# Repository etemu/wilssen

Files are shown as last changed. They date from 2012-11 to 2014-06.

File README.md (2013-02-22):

wilssen
=======

Wireless / Wind Logging System for Sourcing ENergy - "Wilssen" is a modular controller for e.g. a wind turbine, it monitors all parameters like phase voltage and efficiency when the wind turbine is generating power.

Compatible with the the Arduino platform.

CC-BY-SA 3.0: This work is Open Source and licensed under
the Creative Commons Attribution-ShareAlike 3.0 License.

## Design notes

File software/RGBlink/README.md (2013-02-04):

#RGBlink

An Arduino library for controlling RGB-leds non-blocking

[Documentation](http://docs.l3kn.de/RGBlink/)

by Leon (l3kn) Rische

CC-BY-SA 3.0: This work is Open Source and licensed under the Creative Commons Attribution-ShareAlike 3.0 License.

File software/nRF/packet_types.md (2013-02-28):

# Nodes (N-Packet)

Sent by the 000-Node, containing all 'active' nodes (id, ping)
When recvived, add new nodes to own node-list

# Time (T-packet)

When recived and sent by a node which is not in the reciving nodes list of active nodes, add it to the list.
(send a N-packet?), if recived a new node send it back to it and wait for a ping-packet.

# Ping (P-packet)

(Do fancy foo to determine the hop-delay between nodes)

# values (V-packet)

Send sensor values and time, when recived by a non-000 node, forward it to the reciving nodes parent node.
When recived by the 'exit-node' write it to a logfile/cosm

# LED-Pattern (L-packet)

Dent by the 000-node, when recived, forward it to all child-nodes, delay (until every node recived it) and blink the pattern.

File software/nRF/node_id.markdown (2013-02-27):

# Node-ID

15-bit long, octal system > 5x(0..7), in this case only 5x(0..4) because a node can only have 5 receiving-pipes.

The exit node has the ID 00000, the highest possible node is 55555, which means there can be 5^5=3125 nodes.

* Node 00000 has 5 child-nodes, (00001..00005)  
* Node 00001 has 5 child-nodes, (00011..00051)  
* Node 00011 has 5 child-nodes, (00111..00511) 

and so on.

## parent node

To get a nodes parent node, we need to create a mask for the node_id:

To archive this, we take an "full" octal value and shift it right by one digit (3 bits) until there are only 0s in the mask, where there are non-0 digits in the ID.

Then we need to invert the result to a mask of all non-0 digits.

``` c
uint16_t check = 017777;
uint16_t id = 0321;
while ( id & check )
{
	check <<= 3;
	printf("%o\n", check);
	printf("%o\n", id);
}
```
*note: all numbers are octal*

>177770
>000321
>177700
>000321
>177000
>000321

-> mask = 000777

## parent pipe

To communicate each node needs to know, to which of its parents 5 pipes it is connected to, for once 000321 this would be 3, or the node_id - the parent_id shifted to right by the length of the parent_id:

>parent_id = 21  
>node_id = 321  
>node_id - parent_id = 300  
>parent_id.lenght = 2  
>(node_id - parent_id)>>(parent_id.lenght*3) = 3

or written in C

``` c
foo = parent_id
bar = node_id

while(parent_id)
{
	foo>>=3;
	bar>>=3;
}

print bar
```

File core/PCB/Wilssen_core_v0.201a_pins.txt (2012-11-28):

Pinlist

Exported from Wilssen_core_v0.201a.brd at 29.11.2012 00:44:35

EAGLE Version 6.3.0 Copyright (c) 1988-2012 CadSoft

Part     Pad      Net

ATMEGA168/ATMEGA328 1        D3
         10       D6
         11       D7
         12       D8
         13       D9
         14       D10
         15       MOSI
         16       MISO
         17       SCK
         18       VCC
         19       A6
         2        D4
         20       VCC
         21       GND
         22       A7
         23       A0
         24       A1
         25       A2
         26       A3
         27       A4
         28       A5
         29       RST1
         3        GND
         30       RXI
         31       TXO
         32       D2
         4        VCC
         5        GND
         6        VCC
         7        XTAL1
         8        XTAL2
         9        D5

C1       A        VCC
         C        GND

C2       1        VCC
         2        GND

C4       1        GND
         2        A0

C5       1        GND
         2        XTAL1

C6       1        GND
         2        XTAL2

C9       1        USB_VIN
         2        GND

C10      1        VBATT
         2        GND

D1       A        N$2
         C        GND

D4       A        VBATT
         C        N$8

JP1      1        VCC
         10       D9
         11       D10
         12       MOSI
         13       MISO
         14       SCK
         2        GND
         3        D2
         4        D3
         5        D4
         6        D5
         7        D6
         8        D7
         9        D8

JP2      1        GND
         2        VBATT

JP3      1        GND
         2        VBATT
         NC1               *** unconnected ***
         NC2               *** unconnected ***

JP4      1        MISO
         2        VCC
         3        SCK
         4        N$1
         5        RST
         6        GND

JP6      1        GND
         2        USB_VIN

JP8      1        A0
         2        A1
         3        A2
         4        A3
         5        A4
         6        A5
         7        A6
         8        A7

JP9      1        GND
         2        AREF
         3        VCC
         4        RXI
         5        TXO
         6        DTR

Q1       1        XTAL2
         2        XTAL1

R1       1        SCK
         2        N$2

R2       1        GND
         2        A0

R3       1        A0
         2        VBATT

R4       1        RST
         2        VCC

R5       1        N$1
         2        MOSI

R9       1        N$11
         2        N$8

U1       1                 *** unconnected ***
         2        GND
         3        N$11
         4        USB_VIN
         5        VBATT

U2       1        VBATT
         2        GND
         3        VBATT
         4                 *** unconnected ***
         5        VCC

U3       1        D3
         10       D6
         11       D7
         12       D8
         13       D9
         14       D10
         15       MOSI
         16       MISO
         17       SCK
         18       VCC
         19       A6
         2        D4
         20                *** unconnected ***
         21       GND
         22       A7
         23       A0
         24       A1
         25       A2
         26       A3
         27       A4
         28       A5
         29       RST
         3        GND
         30       RXI
         31       TXO
         32       D2
         4        VCC
         5        GND
         6        VCC
         7        XTAL1
         8        XTAL2
         9        D5

X1       D+                *** unconnected ***
         D-                *** unconnected ***
         GND      GND
         GND@1             *** unconnected ***
         GND@2             *** unconnected ***
         GND@3             *** unconnected ***
         GND@4             *** unconnected ***
         ID                *** unconnected ***
         VBUS     USB_VIN

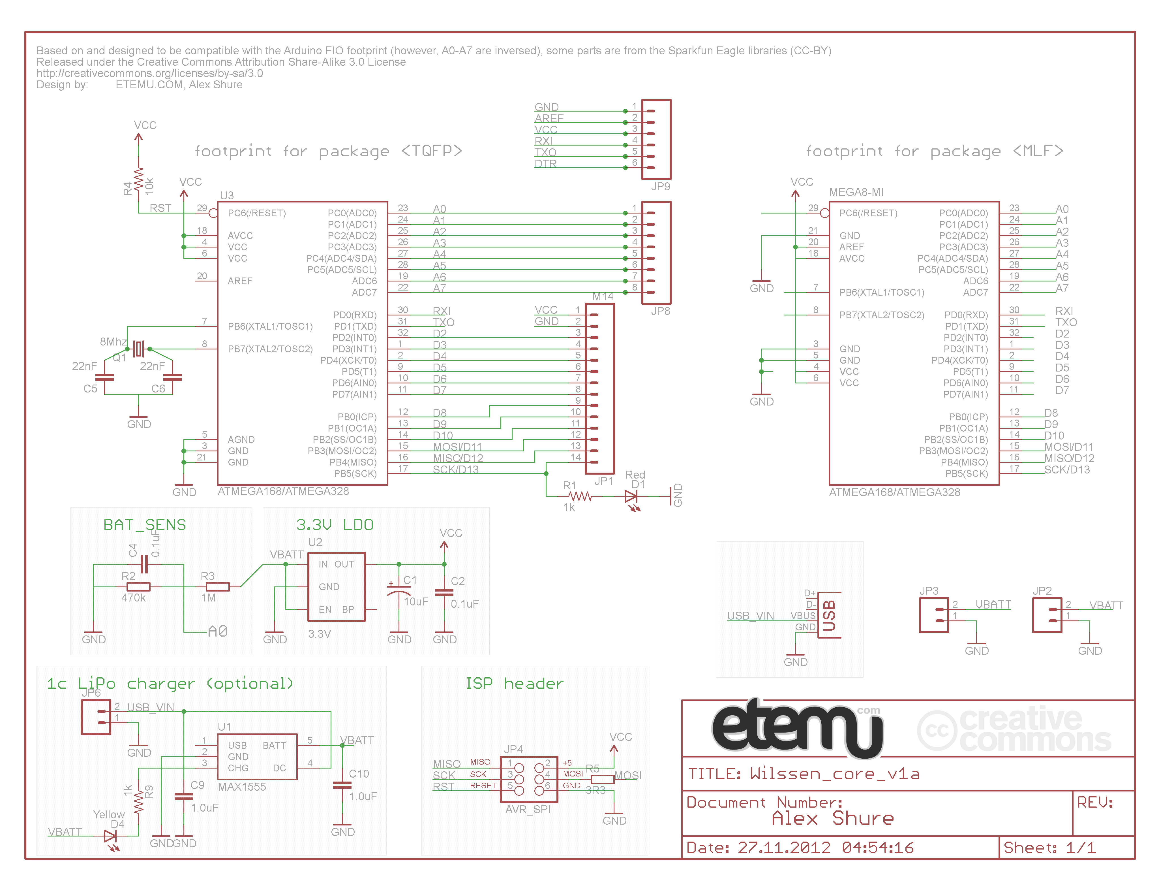
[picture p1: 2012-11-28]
core/PCB/Wilssen_core_v0.201a.sch(201211270426_Wilssen_core_schematic).png

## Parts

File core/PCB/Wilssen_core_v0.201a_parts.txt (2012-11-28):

Partlist

Exported from Wilssen_core_v0.201a.brd at 29.11.2012 00:44:02

EAGLE Version 6.3.0 Copyright (c) 1988-2012 CadSoft

Assembly variant: 

Part                Value               Package   Library             Position (inch)       Orientation

ATMEGA168/ATMEGA328 MEGA8-MI            MLF32     atmel               (0.5 0.825)           R270
C1                  10uF                EIA3216   SparkFun            (0.5 1.35)            R90
C2                  0.1uF               0805      SparkFun            (0.5 1.095)           R90
C4                  0.1uF               0805      SparkFun            (0.5 0.1)             R180
C5                  22nF                0805      SparkFun            (0.775 1.275)         R90
C6                  22nF                0805      SparkFun            (0.225 1.275)         R270
C9                  1.0uF               0402-CAP  SparkFun            (0.5 1.8)             R180
C10                 1.0uF               0402-CAP  SparkFun            (0.5 1.75)            R0
D1                  Red                 LED-0603  SparkFun            (0.5 0.05)            R270
D4                  Yellow              LED-0603  SparkFun            (0.5 1.625)           R90
JP1                 M14                 1X14      SparkFun            (0.05 1.35)           R270
JP2                                     1X02      SparkFun            (0.575 2.1)           MR180
JP3                                     S2B-PH    SparkFun            (1.87 2.475)          R0
JP4                 AVR_SPI             2X3       SparkFun            (0.45 0.525)          R270
JP6                                     1X02      SparkFun            (0.325 2.1)           MR180
JP8                                     1X08      SparkFun-Connectors (0.95 0.05)           R90
JP9                                     1X06      SparkFun-Connectors (0.95 0.85)           R90
Q1                  8Mhz                SM49      crystal             (0.5 1.175)           R0
R1                  1k                  0805      SparkFun            (0.325 0.05)          R0
R2                  470k                R0805     rcl                 (0.5 0.175)           R180
R3                  1M                  R0805     rcl                 (0.5 1.525)           R0
R4                  10k                 1206      SparkFun            (0.65 0.45)           R90
R5                  3R3                 R1206     rcl                 (0.3 0.425)           R180
R9                  1k                  0402-RES  SparkFun            (0.5 1.7)             R180
U1                  MAX1555             SOT23-5   SparkFun            (0.375 1.95)          R270
U2                  3.3V                SOT23-5   SparkFun            (0.625 1.95)          R90
U3                  ATMEGA168/ATMEGA328 TQFP32-08 SparkFun            (0.4996063 0.8253937) R270
X1                  USBSMD              USB-MINIB SparkFun            (0.505 2.35)          R270

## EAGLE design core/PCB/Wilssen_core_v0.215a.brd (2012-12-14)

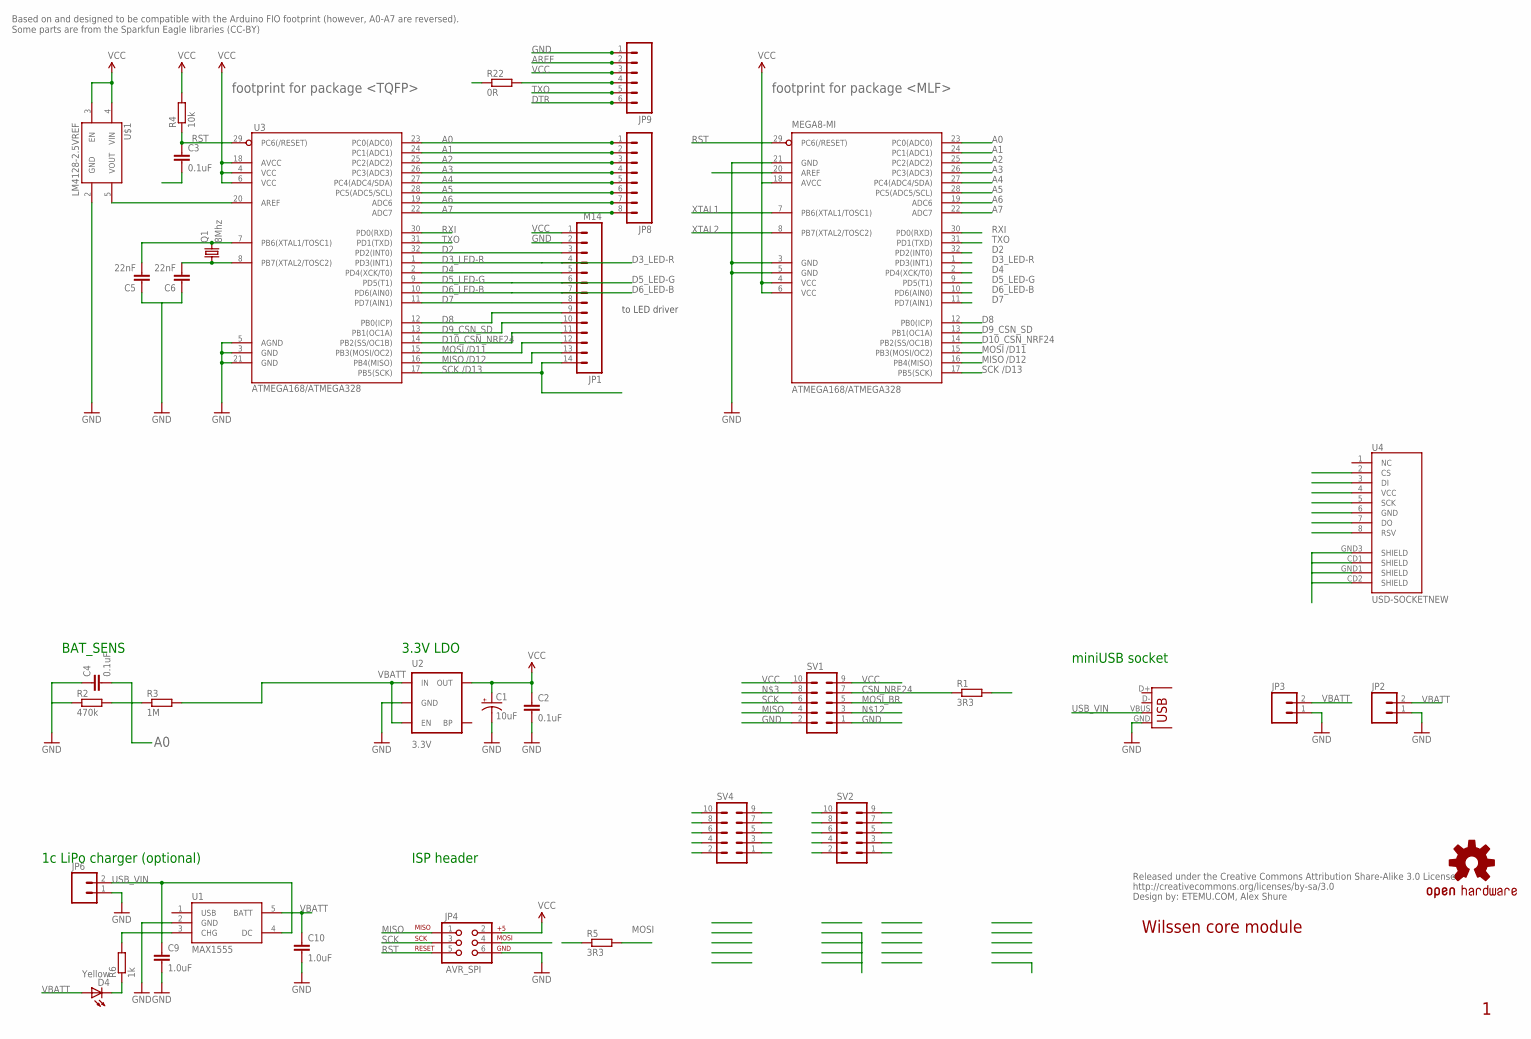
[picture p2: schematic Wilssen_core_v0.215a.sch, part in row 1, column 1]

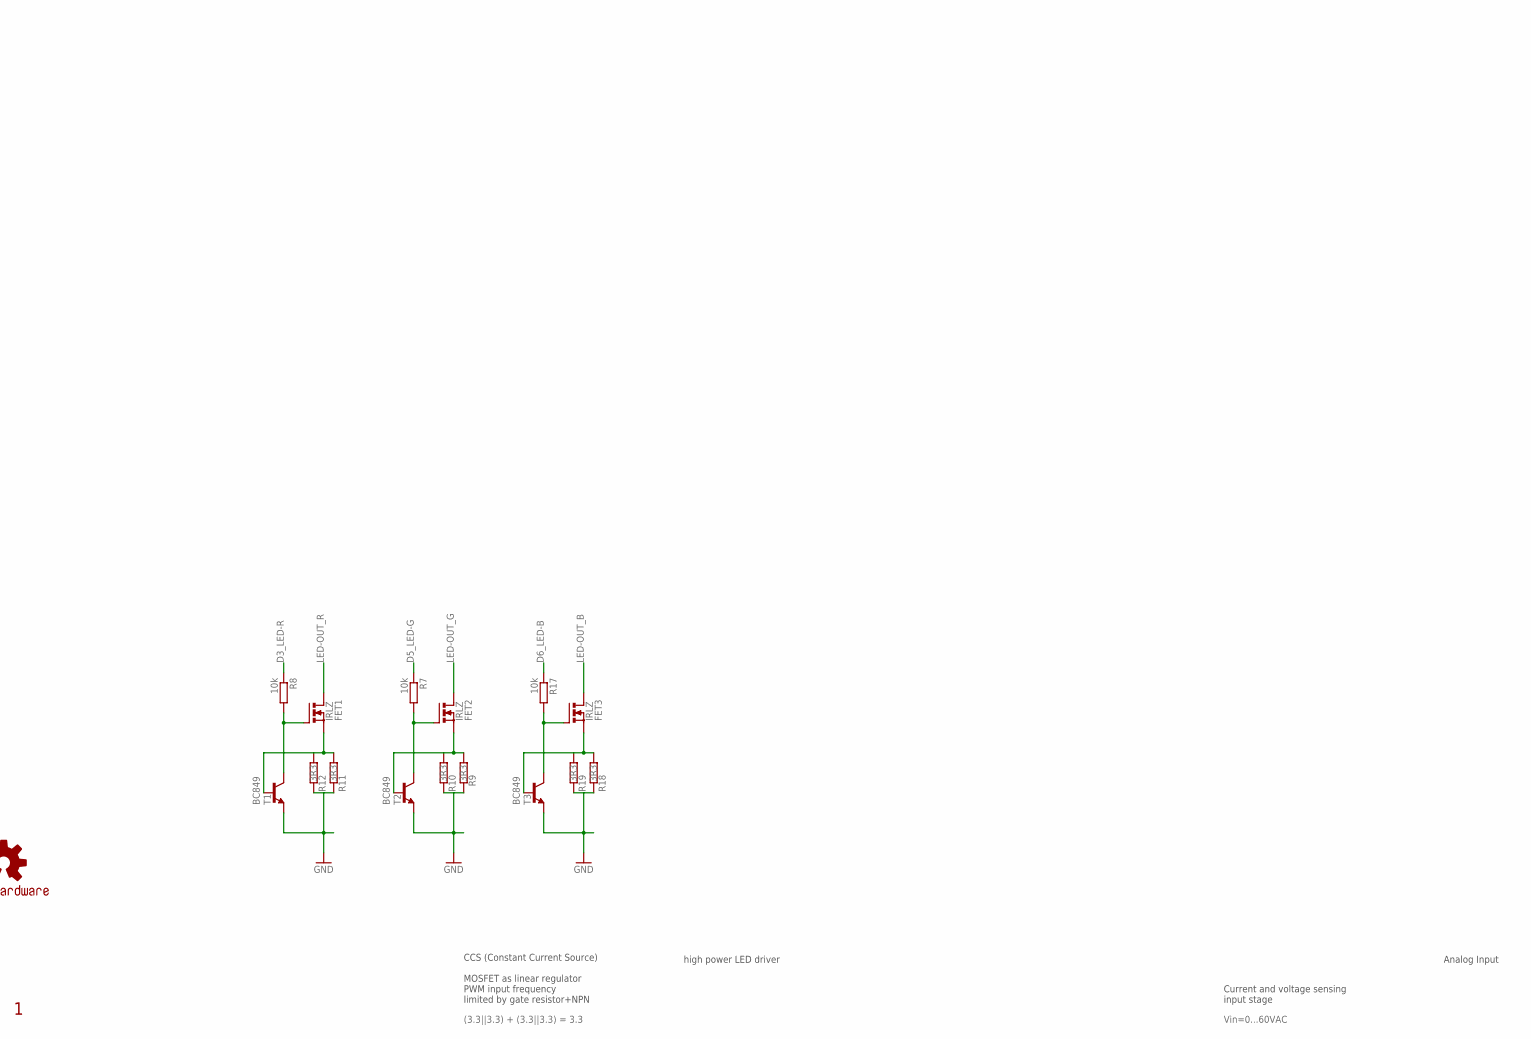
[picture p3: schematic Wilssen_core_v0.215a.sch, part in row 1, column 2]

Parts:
ATMEGA168/ATMEGA328: MEGA8-MI; MLF32
C1: 10uF; EIA3216
C2, C3, C4: 0.1uF; 0805
C5, C6: 22nF; 0805
C9, C10: 1.0uF; 0805
CC_TEXT1: CREATIVE_COMMONS
D4: Yellow; LED-0603
FET1, FET2, FET3: IRLZ; TO220BV
JP1: M14; 1X14
JP2, JP6: M02PTH; 1X02
JP3: M02-JST-2MM-SMT; S2B-PH
JP4: AVR_SPI; 2X3
JP8: M081X08; 1X08
JP9: M06SIP; 1X06
LOGO1: OSHW-LOGOS; OSHW-LOGO-S
Q1: 8Mhz; SM49
R1, R5, R9, R10, R11, R12, R18, R19: 3R3; R1206
R2: 470k; R0805
R3: 1M; R0805
R4, R7, R8, R17: 10k; R0805
R6: 1k; R0805
R22: 0R; R1206
SV1, SV2, SV4: MA05-2
T1, T2, T3: BC849; SOT23
U1: MAX1555; SOT23-5
U2: 3.3V; SOT23-5
U3: ATMEGA168/ATMEGA328; TQFP32-08
U4: USD-SOCKETNEW; MICRO-SD-SOCKET-PP
U$1: LM4128-2.5VREF; SOT23-5
X1: USBSMD; USB-MINIB

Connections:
A0: ATMEGA168/ATMEGA328.23 (PC0(ADC0)), C4.2, JP8.1, R2.2, R3.1, U3.23 (PC0(ADC0))
A1: ATMEGA168/ATMEGA328.24 (PC1(ADC1)), JP8.2, U3.24 (PC1(ADC1))
A2: ATMEGA168/ATMEGA328.25 (PC2(ADC2)), JP8.3, U3.25 (PC2(ADC2))
A3: ATMEGA168/ATMEGA328.26 (PC3(ADC3)), JP8.4, U3.26 (PC3(ADC3))
A4: ATMEGA168/ATMEGA328.27 (PC4(ADC4/SDA)), JP8.5, U3.27 (PC4(ADC4/SDA))
A5: ATMEGA168/ATMEGA328.28 (PC5(ADC5/SCL)), JP8.6, U3.28 (PC5(ADC5/SCL))
A6: ATMEGA168/ATMEGA328.19 (ADC6), JP8.7, U3.19 (ADC6)
A7: ATMEGA168/ATMEGA328.22 (ADC7), JP8.8, U3.22 (ADC7)
AREF: ATMEGA168/ATMEGA328.20 (AREF), JP9.2, U3.20 (AREF), U$1.5 (VOUT)
CSN: SV2.8, SV4.8
CSN_NRF24: R1.1, SV1.7
D2: ATMEGA168/ATMEGA328.32 (PD2(INT0)), JP1.3, U3.32 (PD2(INT0))
D3_LED-R: ATMEGA168/ATMEGA328.1 (PD3(INT1)), JP1.4, R8.1, U3.1 (PD3(INT1))
D4: ATMEGA168/ATMEGA328.2 (PD4(XCK/T0)), JP1.5, U3.2 (PD4(XCK/T0))
D5_LED-G: ATMEGA168/ATMEGA328.9 (PD5(T1)), JP1.6, R7.1, U3.9 (PD5(T1))
D6_LED-B: ATMEGA168/ATMEGA328.10 (PD6(AIN0)), JP1.7, R17.1, U3.10 (PD6(AIN0))
D7: ATMEGA168/ATMEGA328.11 (PD7(AIN1)), JP1.8, U3.11 (PD7(AIN1))
D8: ATMEGA168/ATMEGA328.12 (PB0(ICP)), JP1.9, U3.12 (PB0(ICP))
D9_CSN_SD: ATMEGA168/ATMEGA328.13 (PB1(OC1A)), JP1.10, U3.13 (PB1(OC1A)), U4.2 (CS)
D10_CSN_NRF24: ATMEGA168/ATMEGA328.14 (PB2(SS/OC1B)), JP1.11, R1.2, U3.14 (PB2(SS/OC1B))
DTR: C3.2, JP9.6
GATE1: FET1.G, R8.2, T1.3 (C)
GATE2: FET2.G, R7.2, T2.3 (C)
GATE3: FET3.G, R17.2, T3.3 (C)
GND: ATMEGA168/ATMEGA328.3 (GND), ATMEGA168/ATMEGA328.5 (GND), ATMEGA168/ATMEGA328.21 (GND), C1.C (-), C2.2, C4.1, C5.1, C6.1, C9.2, C10.2, JP1.2, JP2.1, JP3.1, JP4.6, JP6.1, JP9.1, R2.1, R9.2, R10.2, R11.2, R12.2, R18.2, R19.2, SV1.1, SV1.2, SV4.1, SV4.3, SV4.5, SV4.7, T1.2 (E), T2.2 (E), T3.2 (E), U1.2 (GND), U2.2 (GND), U3.3 (GND), U3.5 (AGND), U3.21 (GND), U4.6 (GND), U4.CD1 (SHIELD), U4.CD2 (SHIELD), U4.GND1 (SHIELD), U4.GND3 (SHIELD), U$1.2 (GND), X1.GND
LED-OUT_B: FET3.D
LED-OUT_G: FET2.D
LED-OUT_R: FET1.D
MISO: ATMEGA168/ATMEGA328.16 (PB4(MISO)), JP1.13, JP4.1, SV1.4, SV2.2, SV4.2, U3.16 (PB4(MISO))
MOSI: ATMEGA168/ATMEGA328.15 (PB3(MOSI/OC2)), JP1.12, JP4.4, R5.2, SV2.10, SV4.10, U3.15 (PB3(MOSI/OC2))
MOSI_BR: SV1.5
unnamed: D4.C, R6.1
unnamed: R6.2, U1.3 (CHG)
RST: ATMEGA168/ATMEGA328.29 (PC6(/RESET)), C3.1, JP4.5, R4.1, SV2.6, SV4.6, U3.29 (PC6(/RESET))
RXI: ATMEGA168/ATMEGA328.30 (PD0(RXD)), R22.1, U3.30 (PD0(RXD))
RXI_CON: JP9.4, R22.2
SCK: ATMEGA168/ATMEGA328.17 (PB5(SCK)), JP1.14, JP4.3, SV1.6, SV2.4, SV4.4, U3.17 (PB5(SCK)), U4.5 (SCK)
SRC1: FET1.S, R11.1, R12.1, T1.1 (B)
SRC2: FET2.S, R9.1, R10.1, T2.1 (B)
SRC3: FET3.S, R18.1, R19.1, T3.1 (B)
TXO: ATMEGA168/ATMEGA328.31 (PD1(TXD)), JP9.5, U3.31 (PD1(TXD))
USB_VIN: C9.1, JP6.2, U1.4 (DC), X1.VBUS
VBATT: C10.1, D4.A, JP2.2, JP3.2, R3.2, U1.5 (BATT), U2.1 (IN), U2.3 (EN)
VCC: ATMEGA168/ATMEGA328.4 (VCC), ATMEGA168/ATMEGA328.6 (VCC), ATMEGA168/ATMEGA328.18 (AVCC), C1.A (+), C2.1, JP1.1, JP4.2, JP9.3, R4.2, SV1.9, SV1.10, SV4.9, U2.5 (OUT), U3.4 (VCC), U3.6 (VCC), U3.18 (AVCC), U4.4 (VCC), U$1.3 (EN), U$1.4 (VIN)
XTAL1: ATMEGA168/ATMEGA328.7 (PB6(XTAL1/TOSC1)), C5.2, Q1.2, U3.7 (PB6(XTAL1/TOSC1))
XTAL2: ATMEGA168/ATMEGA328.8 (PB7(XTAL2/TOSC2)), C6.2, Q1.1, U3.8 (PB7(XTAL2/TOSC2))

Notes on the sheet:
Wilssen core module
/D11
/D12
/D13
Based on and designed to be compatible with the Arduino FIO footprint (however, A0-A7 are reversed). Some parts are from the Sparkfun Eagle libraries (CC-BY)
ETEMU.COM, Alex Shure
footprint for package <TQFP>
footprint for package <MLF>
1c LiPo charger (optional)
ISP header
3.3V LDO
BAT_SENS
miniUSB socket
(3.3||3.3) + (3.3||3.3) = 3.3
CCS (Constant Current Source) MOSFET as linear regulator PWM input frequency limited by gate resistor+NPN
high power LED driver
to LED driver
Vin=0...60VAC
Current and voltage sensing input stage
Analog Input

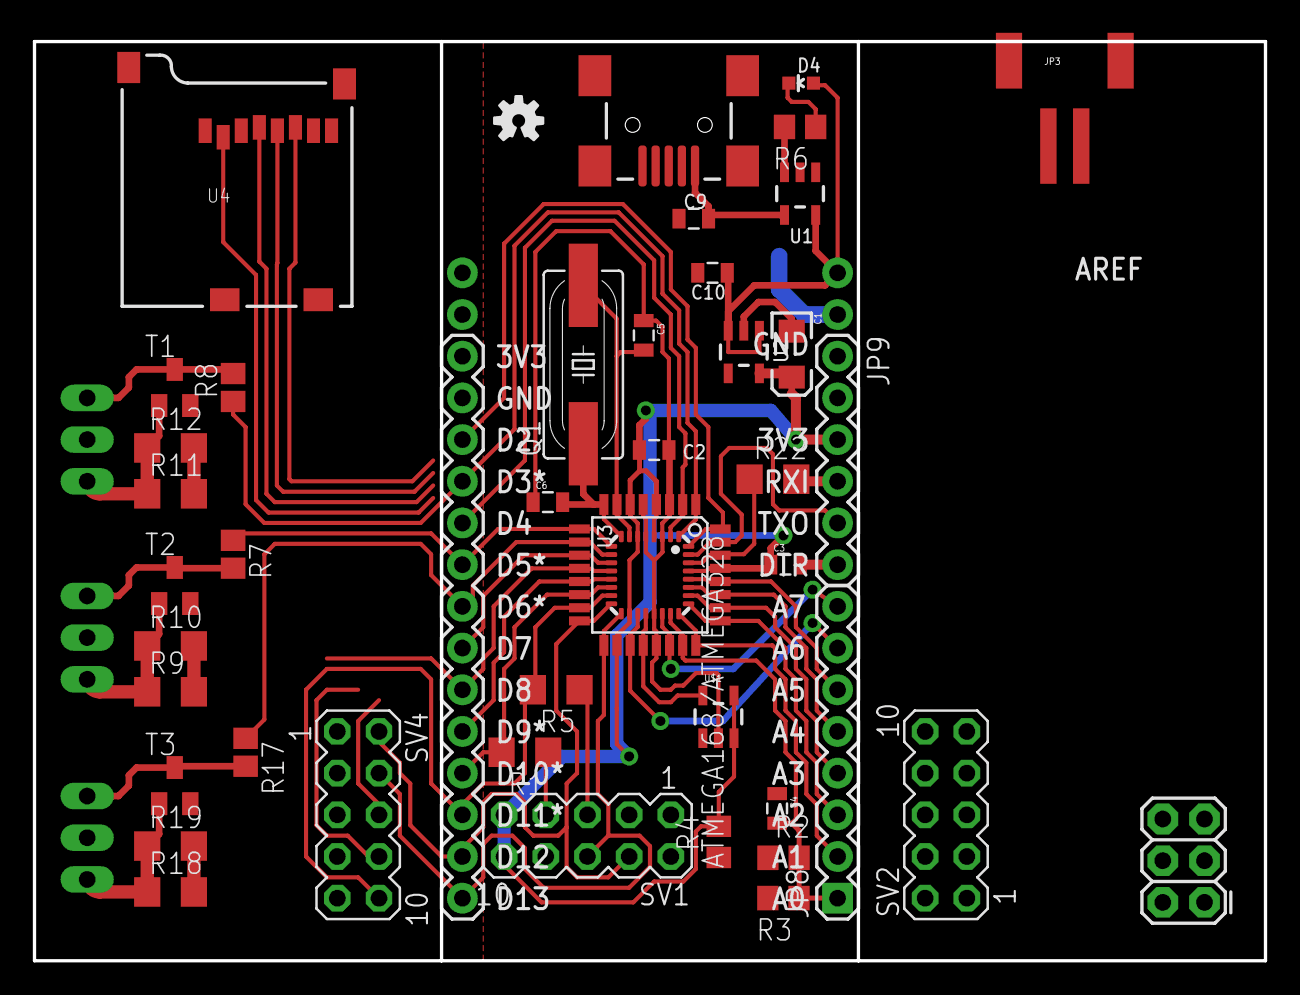
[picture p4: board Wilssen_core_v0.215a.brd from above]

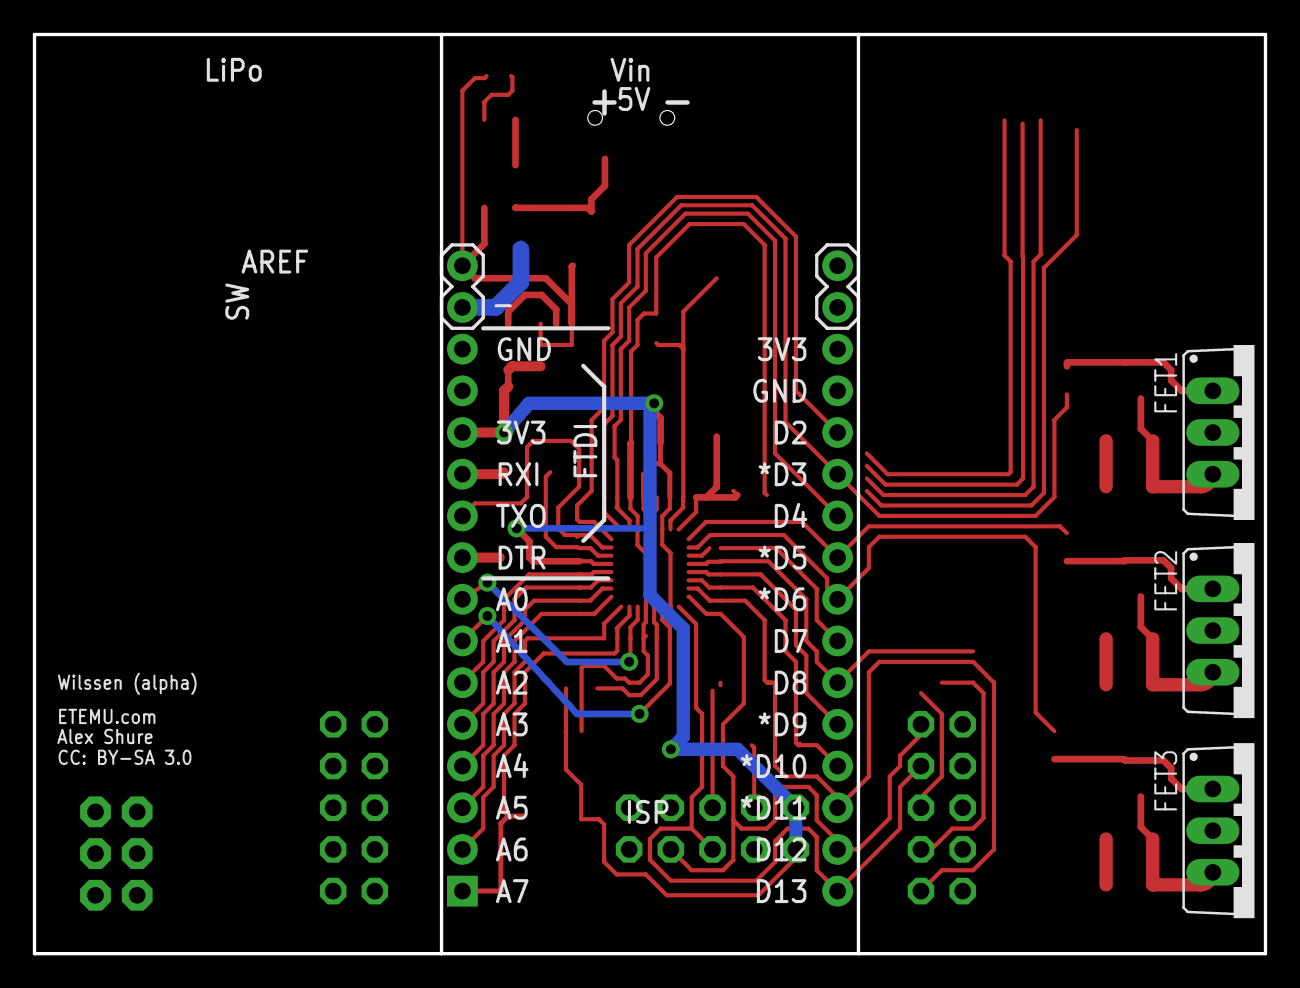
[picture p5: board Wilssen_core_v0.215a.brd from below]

Board: 2 copper layers, 75.0 x 56.0 mm, 51 parts (5 on the bottom side), 42 nets.

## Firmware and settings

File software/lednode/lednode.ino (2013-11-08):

#include <RF24Network.h>
#include <RF24.h>
#include <SPI.h>
#include <stdarg.h>
#include <Adafruit_NeoPixel.h>
#include <EEPROM.h>
#define DEBUG 0 // debug mode with verbose output over serial at 115200 bps
#define USE_EEPROM // read nodeID and network settings from EEPROM at bootup, overwrites nodeID and MAC.
#define LEDPIN 6
#define KEEPALIVE 1 // keep connections alive with regular polling to node 0

Adafruit_NeoPixel leds = Adafruit_NeoPixel(8, LEDPIN, NEO_GRB + NEO_KHZ800); // number of pixels in strip, pin number, pixel type flags

RF24 radio(A0,10); // CE, CS. CE at pin A0, CSN at pin 10
RF24Network network(radio); // mesh network layer 

const unsigned long interval = 30000; // KEEPALIVE interval in [ms]
byte sweep=0;
byte nodeID = 1; // Unique Node Identifier (2...254) - also the last byte of the IPv4 adress, not used if USE_EEPROM is set
uint16_t this_node = 00; // always begin with 0 for octal declaration, not used if USE_EEPROM is set
// Debug variables, TODO: don't initialize if DEBUG is set to 0
unsigned long iterations=0;
unsigned long errors=0;
unsigned int loss=0;
unsigned long p_sent=0;
unsigned long p_recv=0;
// Variables for the 32bit unsigned long Microsecond rollover handling
static unsigned long microRollovers=0; // variable that permanently holds the number of rollovers since startup
static unsigned long halfwayMicros = 2147483647; // this is halfway to the max unsigned long value of 4294967296
static boolean readyToRoll = false; // tracks whether we've made it halfway to rollover

const short max_active_nodes = 32; // the size of the array with active nodes
uint16_t active_nodes[max_active_nodes];
short num_active_nodes = 0;
short next_ping_node_index = 0;
unsigned long last_time_sent;
unsigned long updates = 0; // has to be changed to unsigned long if the interval is too long
void add_node(uint16_t node);
boolean send_T(uint16_t to);
void send_L1(int to, int _b);
void handle_K(RF24NetworkHeader& header);
void handle_L(RF24NetworkHeader& header);
void handle_T(RF24NetworkHeader& header);
void handle_B(RF24NetworkHeader& header);
void ledupdate(byte* ledmap);
void p(char *fmt, ... );
void ledst(int sta=127);

bool strobe=1; 

void setup(void)
{
  pinMode(A6, INPUT); // some nodes have a sense wire to the 3v3 for the NRF24 module via external LDO
  pinMode(A7, INPUT); // see above
  leds.begin(); // the 8 LEDs
  leds.show(); // Initialize all pixels to 'off'
  pinMode(A1, OUTPUT); // GND for the NRF24 module
  digitalWrite(A1, LOW); // GND for the NRF24 module
  pinMode(2, OUTPUT); // Vcc for the NRF24 module, 3.5-5V output to an LDO supplying 3.3V
  digitalWrite(2, HIGH); // Vcc for the NRF24 module activated. Shutdown with LOW.
  Serial.begin(115200);
  delay(128); // wait for the serial interface to boot up
  while (!Serial) {
    ; // wait for serial port to connect.
  }
#ifdef USE_EEPROM
  nodeID=EEPROM.read(0);
  Serial.print(F("EEPROM, "));
#endif
  Serial.println(nodeID);
  Serial.print(F("Network ID (oct): "));
#ifdef USE_EEPROM
  this_node = ((int) EEPROM.read(15)*256) + ((int) (EEPROM.read(16)));
  Serial.print(F("EEPROM, "));
#endif
  Serial.print(this_node,OCT);
  Serial.print(F(", (dec): "));
  Serial.print(this_node,DEC);
  Serial.println();
  SPI.begin(); // SPI for the NRF24
  radio.begin(); // init of the NRF24
  // The amplifier gain can be set to RF24_PA_MIN=-18dBm, RF24_PA_LOW=-12dBm, RF24_PA_MED=-6dBM, and RF24_PA_MAX=0dBm.
  radio.setPALevel(RF24_PA_MAX); // transmitter gain value (see above)
  network.begin( 1, this_node ); // fixed radio channel, node ID
  Serial.print(F("UID: \n"));
  p("%010ld: Starting up\n", millis());
  colorWipe(leds.Color(100, 0, 0), 100); // Red
  colorWipe(leds.Color(0, 100, 0), 100); // Green
  colorWipe(leds.Color(0, 0, 100), 100); // Blue
  colorWipe(leds.Color(0, 0, 0), 0); // clear
  ledst(2);
  //  radio.printDetails(); // print NRF config registers. Does not work with NRF24network right now?!
}

void loop(void)
{
  ledst();
  network.update();
  updates++;
  while ( network.available() ) // while there are packets in the FIFO buffer
  {
    ledst(3); // light up status LED with pattern #3
    RF24NetworkHeader header; // initialize header
    network.peek(header); // preview the header, but don't advance nor flush the packet
    switch (header.type) // check which packet type we received
    {
    case 'K':
      handle_K(header);
      break;
    case 'L':
      handle_L(header);
      break;
    case 'T':
      handle_T(header);
      break;
    case 'B':
      handle_B(header);
      break;      
    default:
      network.read(header,0,0); // if none of the above packet types matched, read out and flush the buffer
      if (DEBUG) {
        Serial.print(F("            undefined packet type: ")); // print the unrecognized packet type
        Serial.print(header.type);
        Serial.println();
      }
      break;
    };
    ledst(); // reset the status LED to the default pattern
  }
  unsigned long now = millis();
  unsigned long nowM = micros();
  if ( now - last_time_sent >= interval ) // non-blocking check for start of debug service routine interval
  {
    ledst(1); //red
    /* // unsigned long int rollover checking:
     Serial.print(microsRollover()); // how many times has the unsigned long micros() wrapped?
     Serial.print(":"); //separator 
     Serial.print(nowM); //micros();
     Serial.print("\n"); //new line
     */
    if (DEBUG) {
      p("%010ld: %ld Hz\n",millis(),updates*1000/interval);
    }
    updates = 0;
    last_time_sent = now;
    if (KEEPALIVE) {
      uint16_t to = 00;
      bool ok = 0;
      if ( to != this_node)
      {
        unsigned long nowM = micros();
        ok = send_T(to);
        if (DEBUG) p(" in %ld us.\n", (micros()-nowM) );
        if (ok) p_sent++;
        if (!ok)
        {
          errors++;
          if (DEBUG) {
            p("%010ld: No ACK timeout.\n", millis()); // An error occured, need to stahp!
          }
        }
        iterations++;
        /*
      Serial.print("loop: \t\t");
         Serial.println(iterations);
         Serial.print("errors: \t\t");
         Serial.println(errors);     
         Serial.print("send error in %: \t");
         Serial.println(errors*100/iterations);
         Serial.print("pkts sent    : \t");
         Serial.println(p_sent);
         Serial.print("pkts received: \t");
         Serial.println(p_recv);
         Serial.print("replies in %: \t");
         Serial.println(p_recv*100/(p_sent-1));
         */
      }
    }
   /*
    if ( this_node == 00){
      for (short _i=0; _i<num_active_nodes; _i++) {
        send_L1(active_nodes[_i],(byte) sweep&0xFF);
      }
      strobe=!strobe;
    }
    */
    if ( this_node == 00){
      send_L1(01,(byte) sweep&0xFF);
      //send_L1(00,(byte) sweep&0xFF);
      strobe=!strobe;
    }
  }
}
/* WIP DRAFT, TBD
 C voltage (1-24 byte) fixed point values
 D current (1-24 byte) fixed point values
 E battery voltage (2 byte)
 F error code + error value
 G 
 K draft for home automation packet
 L LED map
 T send out timestamp
 V software version, UID, wID, location
 B reply with the just received timestamp (T->B)
 */
 
void send_K(int to){
   byte ledmap[24]={
      1,2,3,
      0,0,1,
      0,0,1,
      0,0,1,
      0,0,1,
      0,0,1,
      0,0,1,
      0,(((byte) millis()&0xFF)/5),1        };

    unsigned long now = millis();
    bool ok = send_L(to, ledmap);
    if (DEBUG) {
      p(" in %ld ms.\n", (millis()-now) );
      if (ok){}
      if (!ok) p("%010ld: send_K timout.\n", millis()); // An error occured..
    }
  }
 
void send_L1(int to, int _b = 0){
  if ( to != this_node) {      
    byte ledmap[24]={
      1,2,3,
      0,0,_b,
      0,0,_b,
      0,0,_b,
      0,0,_b,
      0,0,_b,
      0,0,_b,
      0,(((byte) millis()&0xFF)/5),_b        };

    unsigned long now = millis();
    bool ok = send_L(to, ledmap);
    if (DEBUG) {
      p(" in %ld ms.\n", (millis()-now) );
      if (ok){}
      if (!ok) p("%010ld: send_L timout.\n", millis()); // An error occured..
    }
    ledst();
  }
}

boolean send_T(uint16_t to) // Send out this nodes' time -> Timesync!
{
  if (DEBUG) p("%010ld: Sent 'T' to   %05o", millis(),to);
  RF24NetworkHeader header(to,'T');
  unsigned long time = micros();
  return network.write(header,&time,sizeof(time));
}

boolean send_L(uint16_t to, byte* ledmap) // Send out an LED map
{
  if (DEBUG) p("%010ld: Sent 'L' to   %05o", millis(),to);
  RF24NetworkHeader header(to,'L');
  return network.write(header,ledmap,24);
}

void ledupdate(byte* ledmap){
  for(uint8_t i=0; i<leds.numPixels(); i++) {
    uint32_t c = leds.Color(ledmap[i*3],ledmap[(i*3)+1],ledmap[(i*3)+2]);
    leds.setPixelColor(i, c);
  }
  leds.show();
}

void handle_K(RF24NetworkHeader& header)
{
  byte kmap[24];
  network.read(header,kmap,sizeof(kmap));
  if (DEBUG) p("%010ld: Recv 'K' from %05o\n", millis(), header.from_node);
  byte ledmap[24]={
    000,000,000, // status LED at 0
    kmap[0],kmap[1],kmap[2], // acc values
    kmap[3],kmap[3],kmap[3], // gyro x
    kmap[4],kmap[4],kmap[4], // gyro y...
    kmap[5],kmap[5],kmap[5],    
    000,000,00,
    000,000,00,
    000,000,0      };
  ledupdate(ledmap);

  if (DEBUG) {
    for(uint16_t i=0; i<sizeof(kmap); i++) { // print out the received packet via serial
      Serial.print(kmap[i]);
      Serial.print(" ");
    }
    Serial.println();
  }
}

void handle_L(RF24NetworkHeader& header)
{
  byte ledmap[24];
  network.read(header,ledmap,sizeof(ledmap));
  if (DEBUG) {
    p("%010ld: Recv 'L' from %05o\n", millis(), header.from_node);
  }
  ledupdate(ledmap);
  if (DEBUG) {
    for(uint16_t i=0; i<sizeof(ledmap); i++) { // print out the received packet via serial
      Serial.print(ledmap[i]);
      Serial.print(" ");
    }
    Serial.println();
  }
}

void handle_T(RF24NetworkHeader& header)
{
  unsigned long time;
  network.read(header,&time,sizeof(time));
  if (DEBUG) {
    p("%010ld: Recv 'T' from %05o:%010ld\n", millis(), header.from_node, time);
  }
  add_node(header.from_node);  
  if(header.from_node != this_node)
  {
    RF24NetworkHeader header2(header.from_node/*header.from_node*/,'B');
    unsigned long nowM = micros();
    if(network.write(header2,&time,sizeof(time)))
      if (DEBUG) {
        p("%010ld: Answ 'B' to   %05o in ", millis(),header.from_node);
        Serial.print(micros()-nowM-16);
        Serial.print(F(" us.\n"));
      }
  }
}

void handle_B(RF24NetworkHeader& header)
{
  p_recv++;
  unsigned long ref_time;
  network.read(header,&ref_time,sizeof(ref_time));
  if (DEBUG) {
    p("%010ld: Recv 'B' from %05o -> %ldus round trip\n", millis(), header.from_node, micros()-ref_time);
  }
}

// Arduino version of the printf()-funcition in C 
void p(char *fmt, ... ){
  char tmp[128]; // resulting string limited to 128 chars
  va_list args;
  va_start (args, fmt );
  vsnprintf(tmp, 128, fmt, args);
  va_end (args);
  Serial.print(tmp);
}

void add_node(uint16_t node) //TODO: remove_node, after a certain timeout...
{
  short i = num_active_nodes;
  while (i--)
    if ( active_nodes[i] == node ) break; // Do we already know about this node?
  if ( i == -1 && num_active_nodes < max_active_nodes )  // If not and there is enough place, add it to the table
  {
    active_nodes[num_active_nodes++] = node; 
    if (DEBUG) {
      p("%010ld: New node: %05o\n", millis(), node);
    }
  }
}

unsigned long microsRollover() { //based on Rob Faludi's (rob.faludi.com) milli wrapper

    // This would work even if the function were only run once every 35 minutes, though typically,
  // the function should be called as frequently as possible to capture the actual moment of rollover.
  // The rollover counter is good for over 584000 years of runtime. 
  //  --Alex Shure

  unsigned long nowMicros = micros(); // the time right now

  if (nowMicros > halfwayMicros) { // as long as the value is greater than halfway to the max
    readyToRoll = true; // we are in the second half of the current period and ready to roll over
  }

  if (readyToRoll == true && nowMicros < halfwayMicros) {
    // if we've previously made it to halfway
    // and the current millis() value is now _less_ than the halfway mark
    // then we have rolled over
    microRollovers++; // add one to the count of rollovers (approx 71 minutes)
    readyToRoll = false; // we're no longer past halfway, reset!
  } 
  return microRollovers;
}

void colorWipe(uint32_t c, uint8_t wait) { //this is blocking with the hardcoded delay...
  for(uint16_t i=0; i<leds.numPixels(); i++) {
    leds.setPixelColor(i, c);
    leds.show();
    delay(wait);
  }
}

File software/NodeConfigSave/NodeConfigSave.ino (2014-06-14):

/*
 * 
 * Stores the nodeID, ethernet MAC and IP to the EEPROM.
 * These values will stay in the EEPROM when the board is
 * turned off and may be retrieved later when booting the node.
 */

#include <EEPROM.h>

// Change these values according to your network setup:
static int wID = 00; // Wireless mesh networt ID, octal value from 00 to 05555
static byte wirelessID[] = {(wID >> 8) & 0xFF, wID & 0xFF}; //TODO: verify endianess
static byte nodeID = wirelessID[1]; // range: 2-254
static byte mac[] = { 0xAE, 0xAD, 0x42, 0x13, 0x37, nodeID }; // choose a unique MAC
static byte ip[] = { 10, 0, 0, nodeID }; // your subnet IP scheme
static byte gw[] = {10, 0, 0, 254}; // your gateway
static byte role = 1; // hardware role: 0 = receiver, 1 = sender. Mostly used for debugging purposes.

byte val[] = {nodeID, mac[0],mac[1],mac[2],mac[3],mac[4],mac[5],ip[0],ip[1],ip[2],ip[3],gw[0],gw[1],gw[2],gw[3],wirelessID[0],wirelessID[1],role};

int addr=0;
void setup()
{
  SaveData();
}

void loop()
{
  delay(1337);
  
}

void SaveData(){
  while (addr < sizeof(val)){
  EEPROM.write(addr, val[addr]);
  // advance to the next address. 
  addr++;
    }
}

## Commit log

2012-11-28 first sketch of the schematic
2012-11-28 v0.201a upload (work in progress!)
    [Wilssen_core_v0.201a.brd, Wilssen_core_v0.201a.sch]
2012-11-29 added external voltage reference
    [Wilssen_core_v0.201a.brd, Wilssen_core_v0.201a.sch]
2012-12-04 moved eagle files to /PCB
    [Wilssen_core_v0.201a.brd, Wilssen_core_v0.201a.sch]
2012-12-05 2.5V voltage reference + tidy up
    [Wilssen_core_v0.201a.brd, Wilssen_core_v0.201a.sch]
2012-12-05 added constant current source
    CCS (high brightness LED driver)
    [Wilssen_core_v0.202a.brd, Wilssen_core_v0.202a.sch]
2012-12-05 CCS2 added
    [Wilssen_core_v0.202a.brd, Wilssen_core_v0.202a.sch]
2012-12-05 v0.203a - high power LED driver integrated
    [Wilssen_core_v0.203a.brd, Wilssen_core_v0.203a.sch]
2012-12-05 added the RGBlink Arduino Library
2012-12-06 pins have to be PWM compatible
2012-12-11 v0.204a - rerouted the SMD crystal
    smashed symmetrical layout :-(
    too hard to maintain, too many vias with the symmetry
    [Wilssen_core_v0.204a.brd, Wilssen_core_v0.204a.sch]
2012-12-11 NRF24 header added, ICSP rerouting started
    [Wilssen_core_v0.205a.brd, Wilssen_core_v0.205a.sch, Wilssen_core_v0.206a.brd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]
2012-12-12 switched to 10 pin ICSP, began to label microSD
    [Wilssen_core_v0.207a.brd, Wilssen_core_v0.207a.sch, Wilssen_core_v0.208a.brd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]
2012-12-12 3V3 LDO routed
    [Wilssen_core_v0.209a.brd, Wilssen_core_v0.209a.sch, Wilssen_core_v0.210a.brd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]
2012-12-12 added invert option for low-pwm led drivers
    [RGBlink.cpp]
2012-12-13 shrunk board size to under 60mm height
    circumvent xtal to eliminate 2 vias.
    [Wilssen_core_v0.211a.brd, Wilssen_core_v0.211a.sch, Wilssen_core_v0.212a.brd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]
2012-12-13 power supply rerouted + started to use bottom layer
    [Wilssen_core_v0.213a.brd, Wilssen_core_v0.213a.sch, Wilssen_core_v0.214a.brd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]
2012-12-14 added selftest + minor fixes
    [RGBlink.cpp]
2012-12-22 arduino checksum code
2013-01-09 Create 3.3V LDO regulator
    We are looking for a cheap 3.3 V LDO regulator:
    Must have:
    -low idle current for sleep/standby mode
    -low Vdrop for usage with a 1c LiPo battery as a power supply (3.6-4.2V)
    -Vdrop of 0.4V would be nice.
2013-01-09 Update 3.3V LDO regulator
2013-01-11 Update hardware/3.3V LDO regulator
    Added some more regulators
2013-02-05 Create client.ino
    Arduino nRf Temperature sensor with fancy blinking lights
2013-04-04 new update rate calc + NRF24 SPI pinout
    SPI connection changed to CSN at pin 9 and CE at pin 8.
    update rate approx 20k/s
2013-09-14 wip led remote control
2013-09-28 Implemented wireless LED control
    up to 8 RGB LEDs simultaneously
2013-09-29 wip implement EEPROM config
    [led_patterns_sheet.ods]
2013-09-29 wip LED patterns
2013-09-29 node EEPROM config endianess fix
    [NodeConfigSave.ino, lednode.ino]
2013-10-01 strobe all active node LEDs
    [led_patterns_sheet.ods]
2013-11-05 make KEEPALIVE optional, wip implement switchcube
2013-11-05 outsource LED patterns to led_patterns file
2013-11-05 fix integer overflow in updates
    [lednode.ino]
2013-11-06 push switchcube project from local repo
2014-03-01 custom bootloader boards.txt for Arduino IDE

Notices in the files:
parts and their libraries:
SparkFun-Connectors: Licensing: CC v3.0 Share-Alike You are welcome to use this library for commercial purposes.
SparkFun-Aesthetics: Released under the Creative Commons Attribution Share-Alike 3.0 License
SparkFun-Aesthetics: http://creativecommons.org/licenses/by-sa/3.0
